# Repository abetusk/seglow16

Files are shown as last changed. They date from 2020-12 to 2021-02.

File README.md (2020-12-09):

seglow16
---

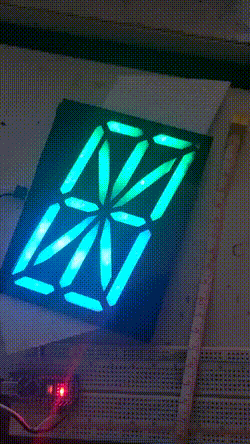
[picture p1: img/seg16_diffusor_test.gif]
16seg demo (https://www.youtube.com/watch?v=fP0ltvnkAXw)


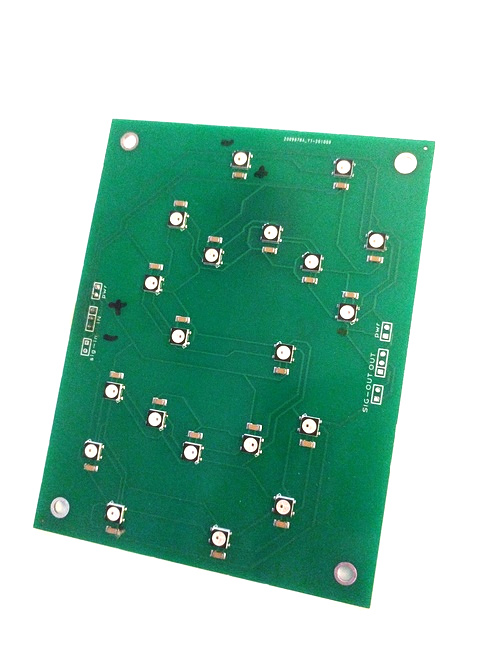
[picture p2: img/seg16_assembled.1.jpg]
seg16 board


A 16 segment digit (base board) using WS2812B/SK6812 5050 parts.
Size should be about 5.2"x3.9" (132mmx100mm).

The segments can be chained, just like a normal WS2812b strip,
and each board has separate power and signal lines to facilitate
ease of driving multiple digits chained together.

A small example script to "drive" the digits is located in the
[`src/` directory](https://github.com/abetusk/seglow16/blob/main/src/seglow16-example.ino).

---

Made with [MeowCAD](https://meowcad.com/project?projectId=4983569d-bf97-47ea-8737-0bbebbcf3797).

| | |
|---|---|
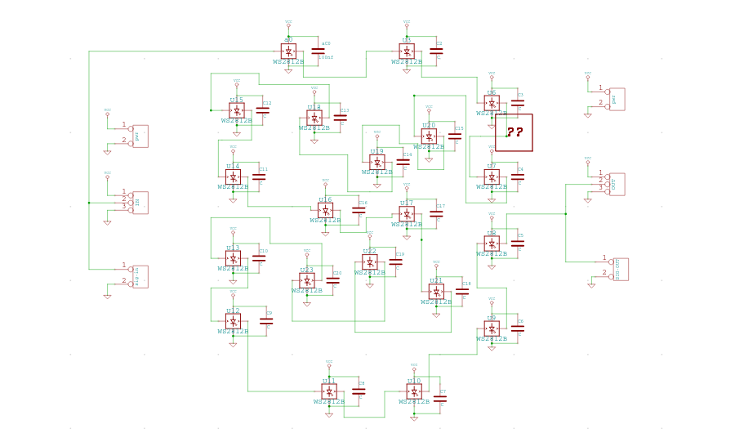
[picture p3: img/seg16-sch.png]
sch
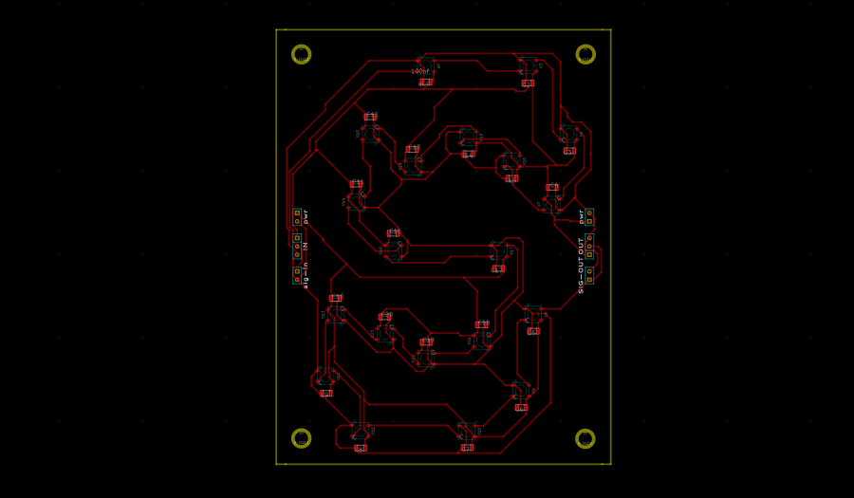
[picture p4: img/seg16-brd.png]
brd
|  |  |

The current version is located in `export_v0.1.1`.

A skinnier version of the digit is located in `export_v0.2.0` but this hasn't been tested.

---

The order of the LEDs is given by the following diagram:

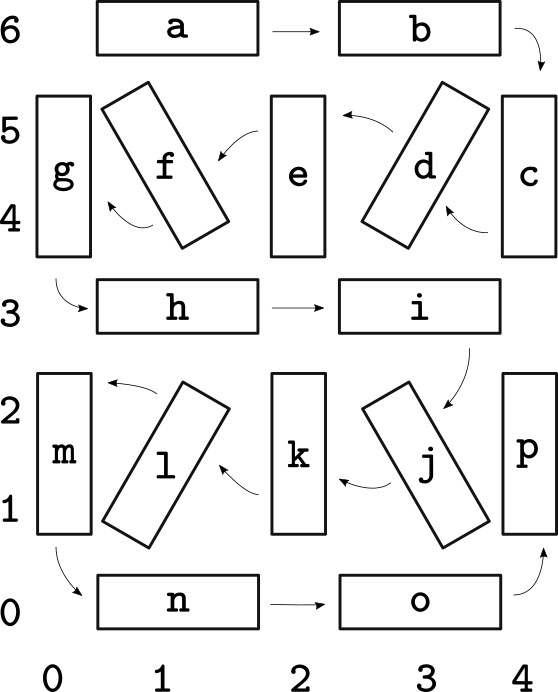
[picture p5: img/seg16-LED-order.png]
seg6 LED order


---

For creating dividers for separating the segments or for creating the digit masks,
the SVG files can be used, located in the [`aux/` directory](https://github.com/abetusk/seglow16/blob/main/aux).

Fabrication
---

The current version is located in the [export_v0.1.1](https://github.com/abetusk/seglow16/blob/main/export_v0.1.1/gerber/seg16_v0.1.1.zip)
directory.

If you would like to use JLCPCB's service to fab boards, the BOM and CPL file are located in
the [`aux/jlcpcb` directory](https://github.com/abetusk/seglow16/blob/main/aux/jlcpcb).

License
---

Everything in this directory, unless explicitly denoted otherwise, is
under a CC0 license.

CC0

CC0 (https://creativecommons.org/publicdomain/zero/1.0/)

cc0

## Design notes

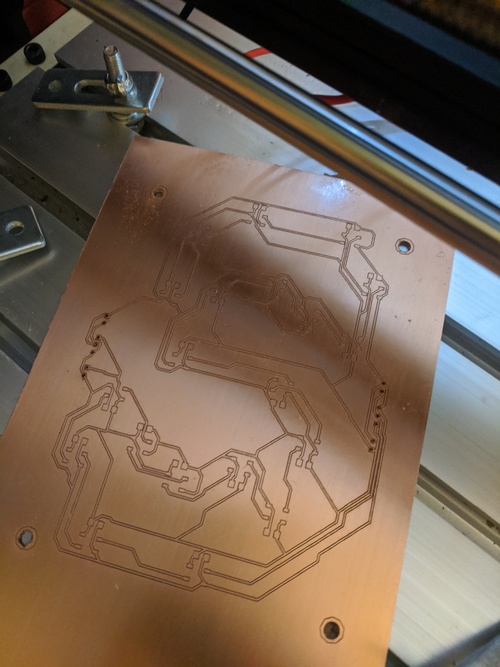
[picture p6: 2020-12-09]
img/seg16_pcb.jpg

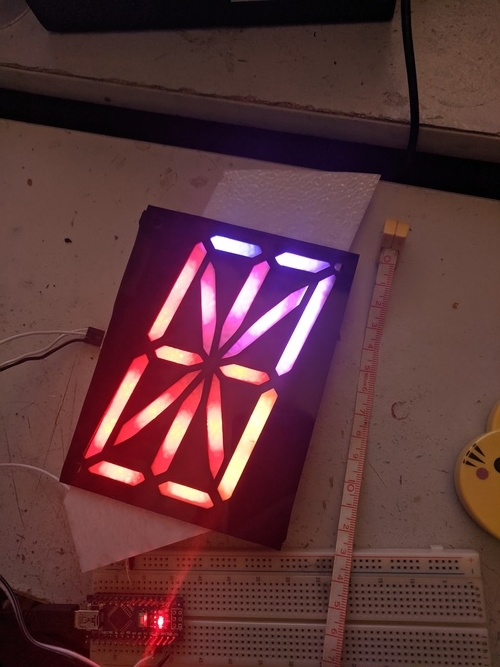
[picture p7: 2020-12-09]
img/seg16_img1.jpg

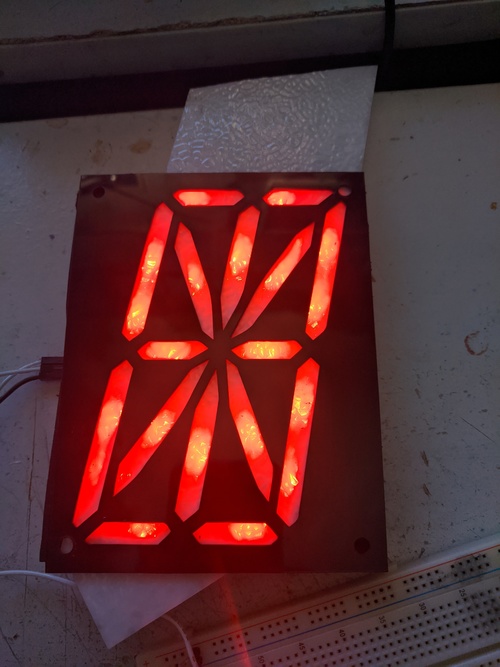
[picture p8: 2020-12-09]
img/seg16_img0.jpg

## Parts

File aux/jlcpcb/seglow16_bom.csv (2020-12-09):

Comment | Designator | Footprint | LCSC Part #（optional）
100nF | aC0 | 1206_C
100nF | C10,C11,C12,C13,C14,C15,C16,C17,C18,C19,C2,C20,C3,C4,C5,C6,C7,C8,C9 | 1206_C
ws2812b | a0 | LED-4_5050
ws2812b | U10,U11,U12,U13,U14,U15,U16,U17,U18,U19,U20,U21,U22,U23,U3,U6,U7,U8,U9 | LED-4_5050

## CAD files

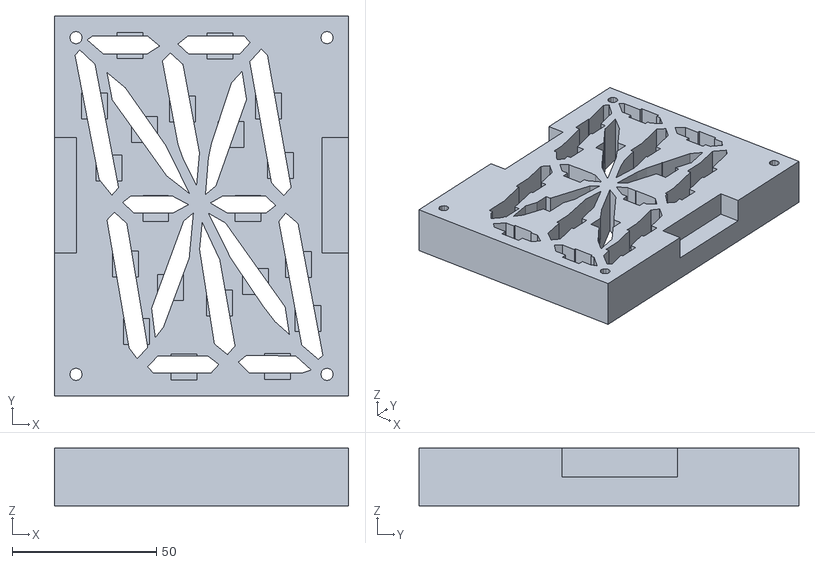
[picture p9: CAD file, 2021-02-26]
aux/seglow16_spacer.stl
101.9 x 131.7 x 20.0

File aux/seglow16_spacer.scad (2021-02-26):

brdr = [
  [13.724739, -160.96538],
  [115.62938, -160.96538],
  [115.62938, -292.63019],
  [13.724739, -292.63019],
  [13.724739, -160.96538]
];


inner_col = [[[32.103054,-278.69291999999996],[49.261385000000004,-278.66801999999996],[51.917216,-280.85355999999996],[48.211044,-284.59788],[29.545903,-284.59788],[26.660615,-283.60952]],
[[22.596154,-278.61696],[24.237569999999998,-279.90757],[29.931525999999998,-275.02929],[37.884029999999996,-232.12463],[35.485676999999995,-229.21268],[31.220273999999996,-232.89434]],
[[39.167781,-266.90365],[34.228941999999996,-271.2762],[35.690704,-261.77613],[56.363804,-232.67098000000001],[62.257853000000004,-229.30267],[54.61755900000001,-244.76842],[43.415824,-261.3797]],
[[65.346066,-241.86003],[60.214921999999994,-274.58819],[55.690822,-278.29008],[53.045893,-275.28821999999997],[58.340521,-245.43789999999996],[64.433465,-232.47342]],
[[62.571182,-278.69239],[79.728879,-278.69239999999996],[83.37029700000001,-282.5137],[81.428999,-284.59189],[61.303506000000006,-284.59889],[58.63001,-281.69579]],
[[86.945686,-279.70824],[89.77461299999999,-275.98166],[97.42799999999998,-231.68262],[94.85868099999999,-228.94302],[90.53878599999999,-232.87122],[83.308993,-275.75684]],
[[81.975025,-262.26427],[70.860176,-231.99322],[67.485047,-229.20661],[68.94612699999999,-244.86502000000002],[77.87092499999999,-268.80416],[80.679046,-272.41169]],
[[74.772736,-223.32869000000002],[89.10904,-223.27639000000002],[92.03324199999999,-225.56494],[88.08730599999998,-229.23364],[74.571071,-229.23364],[69.148427,-226.32714]],
[[42.445053,-223.32879000000003],[57.239090000000004,-223.27429000000004],[61.62301300000001,-225.75030000000004],[55.74122800000001,-229.23373000000004],[42.288842,-229.23373000000004],[38.977286,-226.61197]],
[[40.408984,-218.83102],[47.964465,-176.79776999999999],[43.94972799999999,-172.40157],[41.817705999999994,-174.53357],[33.61045399999999,-220.39517999999998],[36.179775,-223.13751]],
[[63.305468,-222.85755],[59.690573,-219.84618],[49.063849000000005,-189.89028000000002],[50.62369700000001,-180.12454000000002],[54.324422000000006,-184.16107000000002],[61.238130000000005,-205.15951],[62.283389,-210.18359]],
[[66.38702099999999,-219.80461],[71.19391999999999,-210.03718],[72.79106399999999,-205.56375],[78.22279499999999,-176.58047],[75.442315,-173.79998999999998],[71.08699999999999,-177.76092999999997],[65.377416,-208.35906]],
[[69.14911,-174.11637],[72.876398,-170.68607],[69.46993599999999,-167.94065],[49.808353999999994,-167.96555],[47.789027999999995,-170.18269],[51.364115,-174.11637]],
[[83.266081,-167.96585000000002],[102.44949,-167.91205000000002],[104.3179,-169.23687],[98.694274,-174.11667],[83.507161,-174.11667],[79.172328,-171.38523]],
[[108.4893,-174.59006000000002],[100.16723999999999,-217.58265000000003],[95.729199,-223.06731000000002],[93.404412,-220.42238000000003],[101.56478999999999,-177.69556000000003],[106.84703,-172.7135]],
[[95.602503,-190.0306],[76.71512899999999,-216.39032],[68.77243099999998,-222.57147],[77.07384899999998,-205.79427],[91.07077199999998,-185.82034000000002],[97.433449,-180.51689]]];
screw_hole = [
[[23.025949327542058,-169.53900066104035],
[22.243779732896677,-170.32116732750714],
[21.175318000031908,-170.60746],
[20.106856267130958,-170.32116732752309],
[19.32468667247389,-169.539000661068],
[19.03839,-168.47054],
[19.324683339189324,-167.40207511236088],
[20.106853380458915,-166.6199043391034],
[21.17531800008614,-166.33361],
[22.24378261961568,-166.6199043391465],
[23.02595266085374,-167.40207511243545],
[23.312246,-168.47054]],
[[106.31200709600651,-169.53900117503144],
[107.09417748524022,-170.32116790400312],
[108.16264000001273,-170.60745999999997],
[109.23110251477081,-170.32116790399675],
[110.01327290399986,-169.53900117502045],
[110.29957000000002,-168.47053999999997],
[110.01327623728734,-167.40207459841108],
[109.23110540144668,-166.61990376263054],
[108.16263999991789,-166.33361],
[107.09417459848221,-166.6199037626716],
[106.31200376267162,-167.4020745984822],
[106.02571,-168.47054]],
[[106.31200382283255,-284.056564640691],
[107.09417464080357,-283.27439382276754],
[108.162640000065,-282.9881],
[109.23110535925272,-283.27439382280005],
[110.01327617719997,-284.0565646407473],
[110.29957000000002,-285.12503],
[110.01327617716747,-286.19349535930894],
[109.23110535919645,-286.9756661772324],
[108.16263999993502,-287.26196],
[107.0941746407473,-286.9756661771999],
[106.31200382280005,-286.19349535925267],
[106.02571,-285.12503]],
[[23.02594334383412,-284.0565649293669],
[22.243772936547064,-283.27439415610155],
[21.175307999935573,-282.9881],
[20.106843486046966,-283.2743944894673],
[19.324673489467177,-284.05656521809794],
[19.038380000000004,-285.12503],
[19.324673489499343,-286.1934947819577],
[20.106843486102683,-286.97566551056485],
[21.175308000064337,-287.26196],
[22.24377293660286,-286.9756658438662],
[23.02594334386633,-286.1934950705772],
[23.312236999999996,-285.12503]]];

led_pos = [[35.30600000,6.60400000],
[47.75200000,-104.52100000],
[66.42100000,6.73100000],
[64.26200000,-92.20200000],
[78.74000000,-14.09700000],
[73.66000000,-35.56000000],
[67.94500000,-68.96100000],
[15.36700000,-104.39400000],
[4.82600000,-87.75700000],
[8.00100000,-69.08800000],
[14.22400000,-34.79800000],
[18.54200000,-14.09700000],
[25.52700000,-49.65700000],
[57.53100000,-49.65700000],
[31.49600000,-24.00300000],
[61.46800000,-22.35200000],
[52.45100000,-77.08900000],
[35.43300000,-82.42300000],
[22.98700000,-74.93000000],
[48.26000000,-15.11300000]];


module led_out() {
  _dy = -178;
  _dx = 23;
  xf = 1.0;
  yf = 1.0;
  for (i=[0:(len(led_pos)-1)]) {
    translate([xf*led_pos[i][0] + _dx, yf*led_pos[i][1] + _dy, -5]) cube([5,5,50], center=true);
  }

}


module block() {
  _dy = -178;
  _dx = 23;
  xf = 1.0;
  yf = 1.0;

  led_size = 9;

  difference() {
    linear_extrude(height=20) {
      difference() {
        polygon([ brdr[0], brdr[3], brdr[2], brdr[1]]);
        for (i=[0:15]) {
          polygon(inner_col[i]);
        }
        for (i=[0:3]) {
          polygon(screw_hole[i]);
        }

      }
    }

    for (i=[0:(len(led_pos)-1)]) {
      translate([xf*led_pos[i][0] + _dx, yf*led_pos[i][1] + _dy, 0]) cube([led_size,led_size,20], center=true);
    }

    translate([_dx -5, _dy- 45, 0]) cube([10, 40, 20], center=true);
    translate([_dx -5 + 95, _dy- 45, 0]) cube([10, 40, 20], center=true);

  }
}

rotate(180, [0,1,0]) translate([-60, 220]) block();
//color([1,0,0]) rotate(180, [0,1,0]) translate([-60, 220]) led_out();

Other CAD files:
aux/scad/border.scad
aux/scad/led_pos.scad
aux/scad/screw_hole.scad
aux/scad/inner_segment.scad

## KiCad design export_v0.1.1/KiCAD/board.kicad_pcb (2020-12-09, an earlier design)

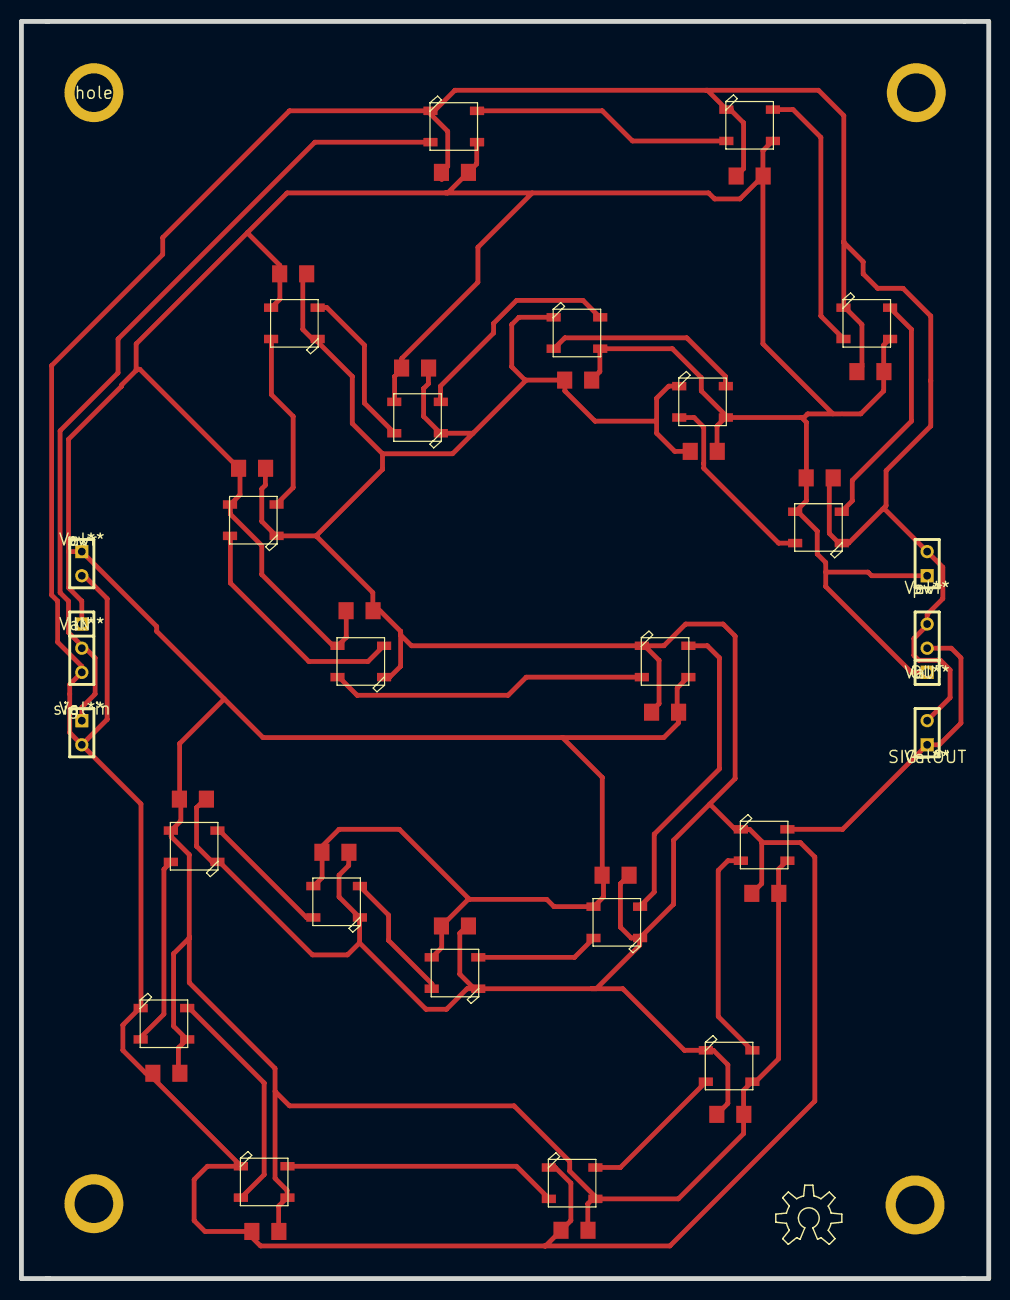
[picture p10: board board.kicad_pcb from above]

Board: 5 copper layers, 101.7 x 132.2 mm, 48 parts (0 on the bottom side), 23 nets.

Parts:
C2, C3, C4, C5, C6, C7, C8, C9, C10, C11, C12, C13, C14, C15, C16, C17, C18, C19, C20: C; C1206
IN: Val**; SIL-3
OUT: Val**; SIL-3
SIG-OUT: Val**; SIL-2
U3, U6, U7, U8, U9, U10, U11, U12, U13, U14, U15, U16, U17, U18, U19, U20, U21, U22, U23: WS2812B; meowWS2812B
a0: WS2812B; meowWS2812B
aC0: 100nf; C1206
hole: meow_hole
pwr: Val**; SIL-2
pwr#2: Val**; SIL-2
ref**: val**; OSHW-LOGO-L
sig-in: Val**; SIL-2

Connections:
unnamed: OUT.2, SIG-OUT.1, U8.2-DOUT
unnamed: C2.2, C3.2, C4.2, C5.2, C6.2, C7.2, C8.2, C9.2, C10.2, C11.2, C12.2, C13.2, C14.2, C15.2, C16.2, C17.2, C18.2, C19.2, C20.2, IN.3, OUT.3, SIG-OUT.2, U3.3-GND, U6.3-GND, U7.3-GND, U8.3-GND, U9.3-GND, U10.3-GND, U11.3-GND, U12.3-GND, U13.3-GND, U14.3-GND, U15.3-GND, U16.3-GND, U17.3-GND, U18.3-GND, U19.3-GND, U20.3-GND, U21.3-GND, U22.3-GND, U23.3-GND, a0.3-GND, aC0.2, pwr.2, pwr#2.2, sig-in.2
unnamed: C2.1, C3.1, C4.1, C5.1, C6.1, C7.1, C8.1, C9.1, C10.1, C11.1, C12.1, C13.1, C14.1, C15.1, C16.1, C17.1, C18.1, C19.1, C20.1, IN.1, OUT.1, U3.1-VDD, U6.1-VDD, U7.1-VDD, U8.1-VDD, U9.1-VDD, U10.1-VDD, U11.1-VDD, U12.1-VDD, U13.1-VDD, U14.1-VDD, U15.1-VDD, U16.1-VDD, U17.1-VDD, U18.1-VDD, U19.1-VDD, U20.1-VDD, U21.1-VDD, U22.1-VDD, U23.1-VDD, a0.1-VDD, aC0.1, pwr.1, pwr#2.1
unnamed: U3.4-DIN, a0.2-DOUT
unnamed: IN.2, a0.4-DIN, sig-in.1
unnamed: U3.2-DOUT, U6.4-DIN
unnamed: U6.2-DOUT, U7.4-DIN
unnamed: U7.2-DOUT, U20.4-DIN
unnamed: U9.4-DIN, U10.2-DOUT
unnamed: U10.4-DIN, U11.2-DOUT
unnamed: U11.4-DIN, U12.2-DOUT
unnamed: U12.4-DIN, U13.2-DOUT
unnamed: U15.4-DIN, U18.2-DOUT
unnamed: U14.4-DIN, U15.2-DOUT
unnamed: U16.2-DOUT, U17.4-DIN
unnamed: U17.2-DOUT, U21.4-DIN
unnamed: U18.4-DIN, U19.2-DOUT
unnamed: U19.4-DIN, U20.2-DOUT
unnamed: U21.2-DOUT, U22.4-DIN
unnamed: U22.2-DOUT, U23.4-DIN
unnamed: U14.2-DOUT, U16.4-DIN
unnamed: U13.4-DIN, U23.2-DOUT
unnamed: U8.4-DIN, U9.2-DOUT

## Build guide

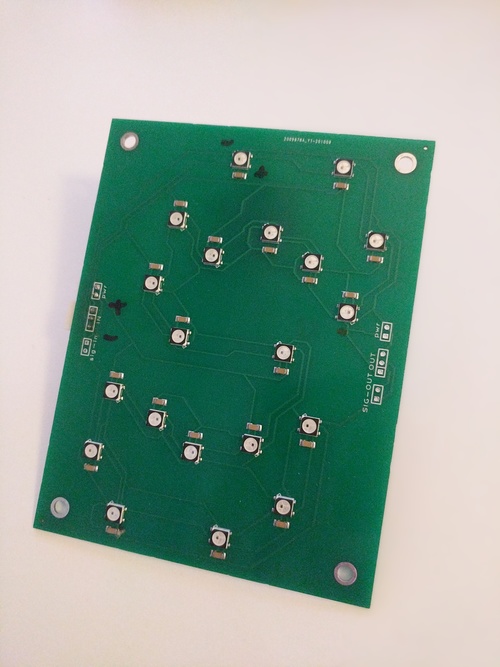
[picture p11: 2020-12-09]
img/seg16_assembled.jpg

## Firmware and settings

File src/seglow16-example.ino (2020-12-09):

// License: CC0
//

// This is a sample Arduino sketch
// to show off basic functionality
// of how to drdive the sixteen segment
// display.
//

#include <Adafruit_NeoPixel.h>
#include <FastLED.h>

#define LED_PIN 6
#define N_DIGIT 10
#define N_DIGIT_LED 20
#define LED_COUNT (N_DIGIT_LED * N_DIGIT)

#define START_CHAR '!'

// end char is inclusive
//
#define END_CHAR '~'


// The number of LEDs in each digit is set by N_DIGIT_LED
// above.
// The WS2812b RGB LEDs act like a normal LED strip.
// In order to get different digits to form, patterns
// are looked up via the `digit_segment`,
// `char_seg_map_start` and `char_seg_map` arrays below.
//
// `char_seg_map` holds character letter codes depending
// on which segment lights up for the ASCII letter being
// displayed, with an index pointer into `char_seg_map`
// being held in `char_seg_map_start`.
//
// Individual WS2812b LED positions are catalogued
// in the `digit_segment`.

// Here is a brief overview of the various functions:
//
// clear_char( char_idx )
//   Clear all LEDs at digit index `char_idx`.
//   Executes a 'show()' at the end.
//
// _clear_char( char_idx )
//   Clear all LEDs at digit index `char_idx`.
//   Does not execute a 'show()' at the end.
//
// display_char( color, char_idx, ch )
//   Display the character `ch` at digit index `char_idx`
//   with color `color`.
//   Executes a 'show()' at the end.
//
// _display_char( color, char_idx, ch )
//   Display the character `ch` at digit index `char_idx`
//   with color `color`.
//   Does not execute a 'show()' at the end.
//
// show_message( color, msg )
//   Display the string `msg` with color `color`.
//   Executes a 'show()' after each digit.
//
// mask_message( color, msg )
//   Display the string `msg` with color `color` without
//   clearing the digit beforehand, allowing whatever
//   base pattern is there to be 'masked'.
//   Does not execute a 'show()' at the end.
//

Adafruit_NeoPixel strip(LED_COUNT, LED_PIN, NEO_GRB + NEO_KHZ800);

uint32_t random_color() {
  return strip.gamma32(strip.ColorHSV( random(65536L) ));
}

// The layout of WS2812b RGB LEDs is
// as follows:
//
//  a         b
//    f     d
// g     e      c
//    h     i
// m     k      p
//     l   j
//   n        o
//
// with 'a' being the first and 'p'
// being the last.
//
// The values in 'digit_segment' correspond
// to the start, length and direction
// of LEDs.
//
// For example, segment 'a' (the upper left
// segment) starts at 0 and has only 1 RGB LED,
// whereas segment 'c' has 2 LEDs and starts
// at LED '2' (the third LED in the digit).
//
// Note direction is unused but left
// here for future reference.
//
// start, length, direction
//
uint8_t digit_segment[] = {

  // a          b          c
  0, 1, 1,   1, 1, 1,   2, 2, 1,

  // d          e          f
  4, 1, 1,   5, 1, 1,   6, 1, 1,

  // g          h          i
  7, 2, 1,   9, 1, 1,  10, 1, 1,

  //  j          k         l
  11, 1, 1,  12, 1, 1, 13, 1, 1,

  //  m          n         o
  14, 2, 1,  16, 1, 1, 17, 1, 1,

  // p
  18, 2, 1
};

uint16_t char_seg_map_start[] = {
0 , // en // !
2 , // ce // "
4 , // cehiknop // #
12 , // abeghiknop // $
22 , // adefghiklop // %
33 , // aefhjmno // &
41 , // e // '
42 , // dko // (
45 , // fkn // )
48 , // defhijkl // *
56 , // ehik // +
60 , // l // ,
61 , // ih // -
63 , // n // .
64 , // dl // /
66 , // abcdglmnop // 0
76 , // cdp // 1
79 , // abchimno // 2
87 , // abcinop // 3
94 , // cghip // 4
99 , // abghjno // 5
106 , // abghimnop // 6
115 , // abcp // 7
119 , // abcghimnop // 8
129 , // abcghip // 9
136 , // ek // :
138 , // el // ;
140 , // dj // <
142 , // ihno // =
146 , // fl // >
148 , // abcik // ?
153 , // abcegimno // @
162 , // abcghimp // A
170 , // abceiknop // B
179 , // abgmno // C
185 , // abceknop // D
193 , // abghmno // E
200 , // abghm // F
205 , // abgimnop // G
213 , // cghimp // H
219 , // abekno // I
225 , // cmnop // J
230 , // dghjm // K
235 , // gmno // L
239 , // cdfgmp // M
245 , // cfgjmp // N
251 , // abcgmnop // O
259 , // abcghim // P
266 , // abcgjmnop // Q
275 , // abcghijm // R
283 , // abghinop // S
291 , // abek // T
295 , // cgmnop // U
301 , // dglm // V
305 , // cgjlmp // W
311 , // dfjl // X
315 , // cghinop // Y
322 , // abdlno // Z
328 , // beko // [
332 , // fj // backslash
334 , // aekn // ]
338 , // lj // ^
340 , // no // _
342 , // f // `
343 , // hikmno // a
349 , // ghimnop // b
356 , // hmn // c
359 , // cikop // d
364 , // hlmno // e
369 , // behik // f
374 , // aeghkn // g
380 , // ghkm // h
384 , // k // i
385 , // ekmn // j
389 , // dejk // k
393 , // gm // l
395 , // hikmp // m
400 , // hkm // n
403 , // hkmn // o
407 , // aeghm // p
412 , // aeghk // q
417 , // hm // r
419 , // aghkn // s
424 , // ghmn // t
428 , // kmn // u
431 , // lm // v
433 , // jlmp // w
437 , // dfjl // x
441 , // ceiop // y
446 , // hln // z
449 , // behko // {
454 , // ek // |
456 , // aiekn // }
461 , // dfg // ~
464 // ...

};

// For simplicity, each digit is encoded
// using a character code ('a' to 'p') to identify
// which segment is activated.
//
// The `char_seg_map` is a long character array,
// with the below using the C preprocessor
// trick that concatenates strings into a
// contiguous string when compiling.
//
// Changes to this array will require changes
// to the `char_seg_map_start` above to make
// sure the sequence can be found.
//
// The length of the encoded digit string
// is taken by subtracting the next element
// in the `char_seg_map_start` array above,
// with the `char_seg_map_start` array
// guaranteeing a final entry that denotes
// the total length of the `char_seg_map`
// (the entry labelled '...' above).
//
char char_seg_map[] =
  // !
  "en"
  // "
  "ce"
  // #
  "cehiknop"
  // $
  "abeghiknop"
  // %
  "adefghiklop"
  // &
  "aefhjmno"
  // '
  "e"
  // (
  "dko"
  // )
  "fkn"
  // *
  "defhijkl"
  // +
  "ehik"
  // ,
  "l"
  // -
  "ih"
  // .
  "n"
  // /
  "dl"
  
  // 0
  "abcdglmnop"
  // 1
  "cdp"
  // 2
  "abchimno"
  // 3
  "abcinop"
  // 4
  "cghip"
  // 5
  "abghjno"
  // 6
  "abghimnop"
  // 7
  "abcp"
  // 8
  "abcghimnop"
  // 9
  "abcghip"

  // :
  "ek"
  
  // ;
  "el"
  
  // <
  "dj"
  
  // =
  "ihno"
  
  // >
  "fl"
  
  // ?
  "abcik"
  
  // @
  "abcegimno"
  

  // A
  "abcghimp"
  // B
  "abceiknop"
  // C
  "abgmno"
  // D
  "abceknop"
  // E
  "abghmno"
  // F
  "abghm"
  // G
  "abgimnop"
  // H
  "cghimp"
  // I
  "abekno"
  // J
  "cmnop"
  // K
  "dghjm"
  // L
  "gmno"
  // M
  "cdfgmp"
  // N
  "cfgjmp"
  // O
  "abcgmnop"
  // P
  "abcghim"
  // Q
  "abcgjmnop"
  // R
  "abcghijm"
  // S
  "abghinop"
  // T
  "abek"
  // U
  "cgmnop"
  // V
  "dglm"
  // W
  "cgjlmp"
  // X
  "dfjl"
  // Y
  "cghinop"
  // Z
  "abdlno"

  // [
  "beko"
  // backslash
  "fj"
  // ]
  "aekn"
  // ^
  "lj"
  // _
  "no"
  // `
  "f"
  
  // a
  "hikmno"
  // b
  "ghimnop"
  // c
  "hmn"
  // d
  "cikop"
  // e
  "hlmno"
  // f
  "behik"
  // g
  "aeghkn"
  // h
  "ghkm"
  // i
  "k"
  // j
  "ekmn"
  // k
  "dejk"
  // l
  "gm"
  // m
  "hikmp"
  // n
  "hkm"
  // o
  "hkmn"
  // p
  "aeghm"
  // q
  "aeghk"
  // r
  "hm"
  // s
  "aghkn"
  // t
  "ghmn"
  // u
  "kmn"
  // v
  "lm"
  // w
  "jlmp"
  // x
  "dfjl"
  // y
  "ceiop"
  // z
  "hln"

  // {
  "behko"
  // |
  "ek"
  // }
  "aiekn"
  // ~
  "dfg"
  ;

void clear_char(uint32_t char_idx) {
  int _s;

  _s = char_idx * N_DIGIT_LED;
  for (int i=_s; i < (_s + N_DIGIT_LED); i++) {
    strip.setPixelColor(i, 0);
  }
  strip.show();
}


void _clear_char(uint32_t char_idx) {
  int _s;

  _s = char_idx * N_DIGIT_LED;
  for (int i=_s; i < (_s + N_DIGIT_LED); i++) {
    strip.setPixelColor(i, 0);
  }

}


void display_char(uint32_t color, uint32_t char_idx, char ch) {
  int _s, _n, _idx, start;
  int rel_idx, rel_n;
  char chseg;

  if ((ch < START_CHAR) || (ch > END_CHAR)) { return; }

  start = char_idx * N_DIGIT_LED;

  _s = char_seg_map_start[ch - START_CHAR];
  _n = char_seg_map_start[ch - START_CHAR + 1] - _s;

  for (int i=0; i<_n; i++) {
    _idx = char_seg_map[_s + i] - 'a';
    rel_idx = digit_segment[ 3*_idx ];
    rel_n = digit_segment[ 3*_idx + 1];
    for (int j=0; j<rel_n; j++) {
      strip.setPixelColor( start + rel_idx + j, color );
    }
    //strip.setPixelColor( start + rel_idx, color );

    //strip.setPixelColor( i, color );
  }

  strip.show();
  
}


void _display_char(uint32_t color, uint32_t char_idx, char ch) {
  int _s, _n, _idx, start;
  int rel_idx, rel_n;
  char chseg;

  if ((ch < START_CHAR) || (ch > END_CHAR)) { return; }

  start = char_idx * N_DIGIT_LED;

  _s = char_seg_map_start[ch - START_CHAR];
  _n = char_seg_map_start[ch - START_CHAR + 1] - _s;

  for (int i=0; i<_n; i++) {
    _idx = char_seg_map[_s + i] - 'a';
    rel_idx = digit_segment[ 3*_idx ];
    rel_n = digit_segment[ 3*_idx + 1];
    for (int j=0; j<rel_n; j++) {
      strip.setPixelColor( start + rel_idx + j, color );
    }
  }

}


void _show_segment(char seg, uint32_t color, uint32_t digit) {
  int _idx, rel_idx, rel_n, start;

  start = digit*N_DIGIT_LED;
  _idx = seg-'a';
  rel_idx = digit_segment[3*_idx];
  rel_n = digit_segment[3*_idx + 1];
  for (int i=0; i<rel_n; i++) {
    strip.setPixelColor(start + rel_idx + i, color);
  }
  
}


void setup() {
  strip.begin();           // INITIALIZE NeoPixel strip object (REQUIRED)
  strip.show();            // Turn OFF all pixels ASAP
  strip.setBrightness(200); // Set BRIGHTNESS to about 1/5 (max = 255)
}

void _test_chars() {
  char ch;
  int digi_idx=0;
  uint32_t color;

  int n=1;

  for (ch = START_CHAR; ch <= END_CHAR; ch++) {
    color = random_color();
    clear_char(digi_idx);
    display_char(color, digi_idx, ch);
    digi_idx = (digi_idx+1)%N_DIGIT;
    delay(1000);
  }

}

void _test_full_brightness() {
  char ch;
  int digi_idx=0;
  uint32_t color;

  int n=1;

  for (int i=0; i<10; i++) { clear_char(i);  }
  for (int i=0; i<(20*10); i++) {
    strip.setPixelColor( i, strip.Color(255,255,255));
  }
  strip.show();
  delay(1000);


}

void _test_random() {
  char ch;
  int digi_idx=0;
  uint32_t color;

  int n=1;

  
  n += random(2);


  for (int i=0; i<n; i++) {

    digi_idx = random(10);
    color = random_color();
    //color = strip.Color(255,255,255);
    ch = random(START_CHAR, END_CHAR + 1);
  
    clear_char(digi_idx);
    display_char(color, digi_idx, ch);
  
    delay( 100 + random(250) );
  }

}

void show_message(uint32_t color, const char *msg) {
  for (int i=0; i<N_DIGIT; i++) { clear_char(i); }
  for (int i=0; i<N_DIGIT; i++) {
    if (msg[i]==0) { break; }
    display_char(color, i, msg[i]);
  }
}


void mask_message(uint32_t color, const char *msg) {
  for (int i=0; i<N_DIGIT; i++) {
    if (msg[i]==0) { break; }
    _display_char(color, i, msg[i]);
  }
}

void randseg() {
  char seg[] = "abcdefghijklmnop";
  int n, idx;
  uint32_t color;

  for (int digit=0; digit<N_DIGIT; digit++) {
    _clear_char(digit);

    n = random(16);
    for (int x=0; x<n; x++) {
      idx = random(16);
      color = random_color();
      _show_segment( seg[idx], color, digit );
    }
  }
  strip.show();
}

// Use FastLEDs simplex noise
// to create some visual effects.
//
void _noi() {
  static uint16_t _t = 0;
  uint8_t res = 0;

  uint32_t c0 = strip.Color(20,0,0);
  uint32_t c1 = strip.Color(55,0,0);
  uint32_t c2 = strip.Color(55,55,0);
  uint32_t c3 = strip.Color(55,55,55);

  uint32_t _c = strip.Color(0,255,255);

  uint16_t digi_pos2d[] = {
    1, 6,  // a
    3, 6,  // b
    4, 5,  // c
    4, 4,  // c
    3, 4,  // d
    2, 3,  // e
    1, 3,  // f
    0, 5,  // g
    0, 4,  // g
    1, 3,  // h
    3, 3 , // i
    3, 2,  // j
    2, 2,  // k
    1, 2,  // l
    0, 2,  // m
    0, 1,  // m
    1, 0,  // n
    3, 0,  // o
    4, 1,  // p
    4, 2   // p
  };
  uint16_t digi_dx = 5;
  uint16_t digi_dy = 7;
  uint16_t _x = 0, _y = 0;
  uint16_t _dx =0, _dy = 0;

  for (uint16_t i=0; i<10; i++) {
    for (uint16_t j=0; j<20; j++) {

      _dx = digi_pos2d[2*j];
      _dy = digi_pos2d[2*j+1];
      
      res = inoise8((uint16_t)(_x + _dx)*64, (uint16_t)(_y + _dy)*64, (uint16_t)_t*4);

      //if (res < 32) { _c = c0; }
      if (res < 64) { _c = c0; }
      else if (res < 150) { _c = c1; }
      else if (res < 215) { _c = c2; }
      else  { _c = c3; }

      strip.setPixelColor(i*20 + j, _c);
    }
    if (i==4) {
      _y += digi_dy;
      _x = 0;
    }
    else {
      _x += digi_dx;
    }

  }

  _t++;
}


void loop() {
  char ch;
  int digi_idx=0;
  uint32_t color;
  static uint32_t _t = 0;
  static uint32_t flip = 8;

  int n=1;

  _t++;
  if (_t >= flip) {
    randseg();
    flip = random(200000);
    _t = 0;
  }
  return;
  
  //_noi();

  if (_t >= flip) {
    mask_message(random_color(), "STAY ALIVE");
    _t = 0;
    flip = random(5,20);
  }
  _t++;
  strip.show();
  return;
  
  if (_t < flip) {
    mask_message(strip.Color(0,128,0), "STAY ALIVE");
  } else {
    mask_message(strip.Color(0,0,128), "STAY ALIVE");
  }
  strip.show();

  _t++;
  if (_t >= (2*flip)) { _t = 0; }
  
  //_test_random();
  return;
  //_test_full_brightness();
  //_test_chars();

  color = strip.Color(255,0,0);
  
  show_message(color, "STAY ALIVE");
  delay(1000);

  return;
}

void step(uint32_t color, uint32_t n, int wait) {
  for (int i=0; i<n; i++) {
    strip.setPixelColor(i, color);
    strip.show();
    delay(wait);
  }
}

// Some functions of our own for creating animated effects -----------------

// Fill strip pixels one after another with a color. Strip is NOT cleared
// first; anything there will be covered pixel by pixel. Pass in color
// (as a single 'packed' 32-bit value, which you can get by calling
// strip.Color(red, green, blue) as shown in the loop() function above),
// and a delay time (in milliseconds) between pixels.
void colorWipe(uint32_t color, int wait) {
  for(int i=0; i<strip.numPixels(); i++) { // For each pixel in strip...
    strip.setPixelColor(i, color);         //  Set pixel's color (in RAM)
    strip.show();                          //  Update strip to match
    delay(wait);                           //  Pause for a moment
  }
}

// Theater-marquee-style chasing lights. Pass in a color (32-bit value,
// a la strip.Color(r,g,b) as mentioned above), and a delay time (in ms)
// between frames.
void theaterChase(uint32_t color, int wait) {
  for(int a=0; a<10; a++) {  // Repeat 10 times...
    for(int b=0; b<3; b++) { //  'b' counts from 0 to 2...
      strip.clear();         //   Set all pixels in RAM to 0 (off)
      // 'c' counts up from 'b' to end of strip in steps of 3...
      for(int c=b; c<strip.numPixels(); c += 3) {
        strip.setPixelColor(c, color); // Set pixel 'c' to value 'color'
      }
      strip.show(); // Update strip with new contents
      delay(wait);  // Pause for a moment
    }
  }
}


// Rainbow cycle along whole strip. Pass delay time (in ms) between frames.
void rainbow(int wait) {
  // Hue of first pixel runs 5 complete loops through the color wheel.
  // Color wheel has a range of 65536 but it's OK if we roll over, so
  // just count from 0 to 5*65536. Adding 256 to firstPixelHue each time
  // means we'll make 5*65536/256 = 1280 passes through this outer loop:
  for(long firstPixelHue = 0; firstPixelHue < 5*65536; firstPixelHue += 256) {
    for(int i=0; i<strip.numPixels(); i++) { // For each pixel in strip...
      // Offset pixel hue by an amount to make one full revolution of the
      // color wheel (range of 65536) along the length of the strip
      // (strip.numPixels() steps):
      int pixelHue = firstPixelHue + (i * 65536L / strip.numPixels());
      // strip.ColorHSV() can take 1 or 3 arguments: a hue (0 to 65535) or
      // optionally add saturation and value (brightness) (each 0 to 255).
      // Here we're using just the single-argument hue variant. The result
      // is passed through strip.gamma32() to provide 'truer' colors
      // before assigning to each pixel:
      strip.setPixelColor(i, strip.gamma32(strip.ColorHSV(pixelHue)));
    }
    strip.show(); // Update strip with new contents
    delay(wait);  // Pause for a moment
  }
}

// Rainbow-enhanced theater marquee. Pass delay time (in ms) between frames.
void theaterChaseRainbow(int wait) {
  int firstPixelHue = 0;     // First pixel starts at red (hue 0)
  for(int a=0; a<30; a++) {  // Repeat 30 times...
    for(int b=0; b<3; b++) { //  'b' counts from 0 to 2...
      strip.clear();         //   Set all pixels in RAM to 0 (off)
      // 'c' counts up from 'b' to end of strip in increments of 3...
      for(int c=b; c<strip.numPixels(); c += 3) {
        // hue of pixel 'c' is offset by an amount to make one full
        // revolution of the color wheel (range 65536) along the length
        // of the strip (strip.numPixels() steps):
        int      hue   = firstPixelHue + c * 65536L / strip.numPixels();
        uint32_t color = strip.gamma32(strip.ColorHSV(hue)); // hue -> RGB
        strip.setPixelColor(c, color); // Set pixel 'c' to value 'color'
      }
      strip.show();                // Update strip with new contents
      delay(wait);                 // Pause for a moment
      firstPixelHue += 65536 / 90; // One cycle of color wheel over 90 frames
    }
  }
}

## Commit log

2020-12-09 JLCPCB related files and svg related files
    [seglow16_bom.csv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]
2021-02-26 adding 3d printable spacer
    * untested and unprinted
    [border.scad, inner_segment.scad, screw_hole.scad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]
